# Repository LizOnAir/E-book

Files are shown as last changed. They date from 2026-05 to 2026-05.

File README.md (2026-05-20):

# E-ink Devboard

This devboard is made to be a e-book that can connect to E-ink display, which make reading more easier and accessible.

## Features:
- low power consume rate
- read offline
- download books online
- no bluelight (YOU CAN READ BEFORE BED)

## CAD Model:
Screenshot 2026-05-19 at 6 27 47 PM
Screenshot 2026-05-19 at 6 27 56 PM
Screenshot 2026-05-19 at 6 28 59 PM

Made in Fusion360.Liz
Access files in [CAD folder](https://github.com/LizOnAir/E-book/tree/main/CAD).

## PCB
Here's my PCB! It was made in KiCad. 
### Schematic
Main board

Screenshot 2026-05-19 at 6 37 28 PM

E-ink Display

Screenshot 2026-05-19 at 6 37 42 PM

### PCB
Screenshot 2026-05-19 at 6 38 33 PM

Access files in [PCB folder](https://github.com/LizOnAir/E-book/tree/main/PCB).

## Firmware
I used Arduino IDE
Mode:
- download books
- add bookmark
- read

Access files in [Firmware folder](https://github.com/LizOnAir/E-book/tree/main/Firmware).

## BOM:
Here should be [everything](https://docs.google.com/spreadsheets/d/18-F1pZoXSL668FSytOyo6Q79A_xbLm0seJzbwmDT4q4/edit?gid=0#gid=0) you need to make this:
- 1x PCBA
- 1x 3.7V Lipo Battery 500mAh
- 1x Tactile buttons
- 1x 7.5 inch E-ink display
- 4x M3 14mm Screws
- 4x M3 OD4.2 L 4 Heatset inserts
- 1x 3d printed case

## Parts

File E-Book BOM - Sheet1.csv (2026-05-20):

Name | Quantity | Price | Source
PCBA | 1 | $56.70 | https://cart.jlcpcb.com/quote?spm=jlcpcb.Public.2006
3.7V Lipo Battery 3000mAh | 1 | $6.63 | https://www.aliexpress.com/item/1005008218024646.html
Tactile buttons | 1 | $1.25 | https://www.aliexpress.com/item/1005006880995108.html
7.5 inch E-ink Display | 1 | $20.90 | https://www.aliexpress.com/item/1005002297292956.html?curPageLogUid=uEnQHYUjn61n
M3 14mm Screws | 1 | $1.26 | https://www.aliexpress.com/item/1005007264845313.html
M3 OD4.2 L 4 Heatset inserts | 1 | $1.05 | https://www.aliexpress.com/item/1005007659182107.html
Total |  | $87.79

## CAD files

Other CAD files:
CAD/E-inkPCB.step
CAD/E-book.f3z

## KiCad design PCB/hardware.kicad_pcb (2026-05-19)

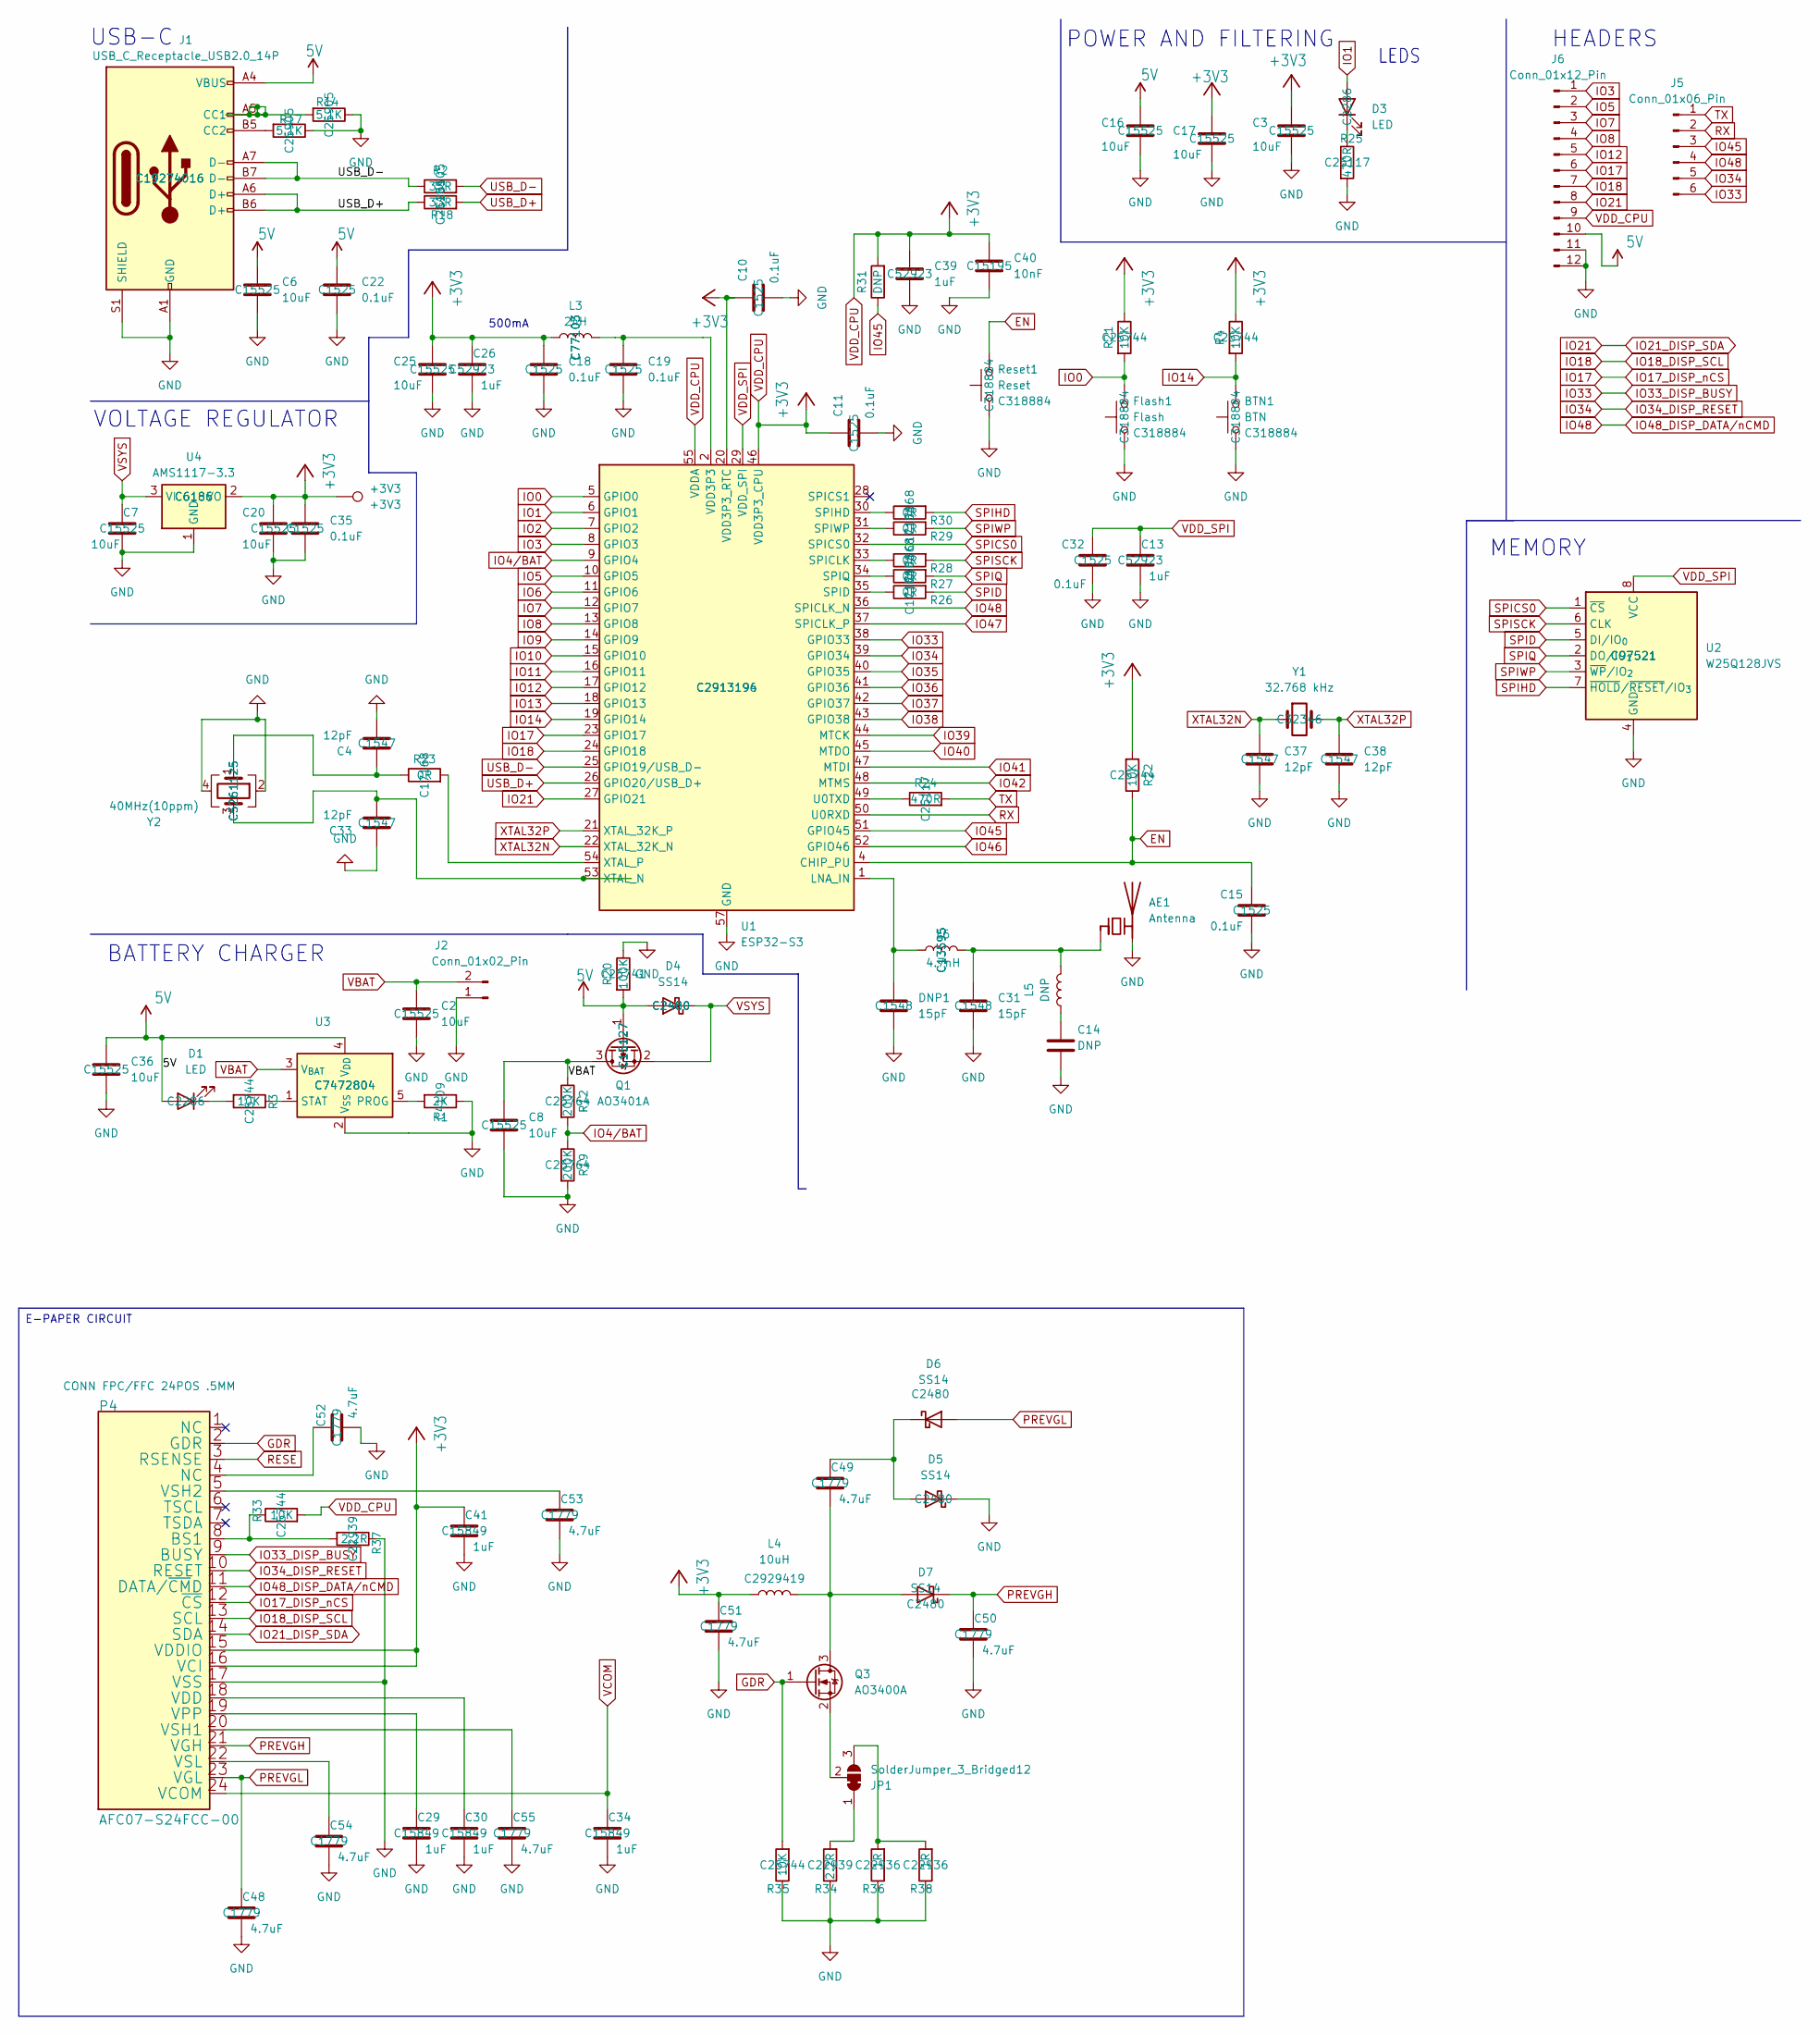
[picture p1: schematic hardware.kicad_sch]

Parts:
+3V3: +3V3; TestPoint_Pad_D1.0mm
AE1: Antenna; Texas_SWRA117D_2.4GHz_Left
BTN1: BTN; SW_Push_1P1T_XKB_TS-1187A; MNF PART NUMBER C318884; LCSC C318884
C2, C3, C6, C7, C8, C16, C17, C20, C25, C36: 10uF; C_0402_1005Metric; MNF PART NUMBER C15525; LCSC C15525
C4, C33, C37, C38: 12pF; C_0402_1005Metric; MNF PART NUMBER C1547; LCSC C1547
C10, C11, C15, C18, C19, C22, C32, C35: 0.1uF; C_0402_1005Metric; MNF PART NUMBER C1525; LCSC C1525
C13, C26, C39: 1uF; C_0402_1005Metric; MNF PART NUMBER C52923; LCSC C52923
C14: DNP; C_0402_1005Metric
C29, C30, C34, C41: 1uF; C_0603_1608Metric; MNF PART NUMBER C15849; LCSC C15849
C31: 15pF; C_0402_1005Metric; MNF PART NUMBER C1548; LCSC C1548
C40: 10nF; C_0402_1005Metric; MNF PART NUMBER C15195; LCSC C15195
C48, C49, C50, C51, C52, C53, C54, C55: 4.7uF; C_0805_2012Metric; MNF PART NUMBER C1779; LCSC C1779
D1, D3: LED; LED_0603_1608Metric; MNF PART NUMBER C2286; LCSC C2286
D4, D5, D6, D7: SS14; D_SMA; MNF PART NUMBER C2480; LCSC C2480
DNP1: 15pF; C_0402_1005Metric; MNF PART NUMBER C1548; LCSC C1548
Flash1: Flash; SW_Push_1P1T_XKB_TS-1187A; MNF PART NUMBER C318884; LCSC C318884
J1: USB_C_Receptacle_USB2.0_14P; USB_C_Receptacle_HCTL_HC-TYPE-C-16P-01A; MNF PART NUMBER C19274016; LCSC C19274016
J2: Conn_01x02_Pin; JST_PH_S2B-PH-K_1x02_P2.00mm_Horizontal
J5: Conn_01x06_Pin; PinHeader_1x06_P1.00mm_Vertical
J6: Conn_01x12_Pin; PinHeader_1x12_P1.00mm_Vertical
JP1: SolderJumper_3_Bridged12; SolderJumper-3_P1.3mm_Bridged12_RoundedPad1.0x1.5mm_NumberL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
L3: 2nH; L_0402_1005Metric; MNF PART NUMBER C77103; LCSC C77103
L4: 10uH; L_Ferrocore_DLG-0403; MNF PART NUMBER C2929419; LCSC C2929419
L5: DNP; L_0402_1005Metric
L6: 4.7nH; L_0402_1005Metric; MNF PART NUMBER C13595; LCSC C13595
P4: AFC07-S24FCC-00; Jushuo_AFC07-S24FCA-00_1x24-1MP_P0.50_Horizontal; MNF PART NUMBER C11057; LCSC C11057
Q1: AO3401A; SOT-23; MNF PART NUMBER C15127; LCSC C15127
Q3: AO3400A; SOT-23; MNF PART NUMBER C20917; LCSC C20917
R1: 2K; R_0402_1005Metric; MNF PART NUMBER C4109; LCSC C4109
R2, R18: 33R; R_0402_1005Metric; MNF PART NUMBER C25105; LCSC C25105
R3, R4, R21, R22, R33, R35: 10K; R_0402_1005Metric; MNF PART NUMBER C25744; LCSC C25744
R12, R19: 200K; R_0402_1005Metric; MNF PART NUMBER C25764; LCSC C25764
R14, R17: 5.1K; R_0402_1005Metric; MNF PART NUMBER C25905; LCSC C25905
R20: 100K; R_0402_1005Metric; MNF PART NUMBER C25741; LCSC C25741
R23, R26, R27, R28, R29, R30: 0R; R_0402_1005Metric; MNF PART NUMBER C17168; LCSC C17168
R24, R25: 470R; R_0402_1005Metric; MNF PART NUMBER C25117; LCSC C25117
R31: DNP; R_0402_1005Metric
R34, R37: 2.2R; R_0603_1608Metric; MNF PART NUMBER C22939; LCSC C22939
R36, R38: 1R; R_0603_1608Metric; MNF PART NUMBER C22936; LCSC C22936
Reset1: Reset; SW_Push_1P1T_XKB_TS-1187A; MNF PART NUMBER C318884; LCSC C318884
U1: ESP32-S3; QFN-56-1EP_7x7mm_P0.4mm_EP4x4mm; MNF PART NUMBER C2913196; LCSC C2913194
U2: W25Q128JVS; SOIC-8_5.3x5.3mm_P1.27mm; MNF PART NUMBER C97521; LCSC C97521
U3: MCP73831-2-OT; SOT-23-5; MNF PART NUMBER C7472804; LCSC C7472804
U4: AMS1117-3.3; SOT-223-3_TabPin2; MNF PART NUMBER C6186; LCSC C6186
Y1: 32.768 kHz; Crystal_SMD_3215-2Pin_3.2x1.5mm; MNF PART NUMBER C32346; LCSC C32346
Y2: 40MHz(10ppm); Crystal_SMD_2520-4Pin_2.5x2.0mm; MNF PART NUMBER C5261125; LCSC C5261125

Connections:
5V: C6.1, C16.1, C22.1, C36.1, D1.2 (A), D4.2 (A), J1.A4 (VBUS), J1.A9 (VBUS), J1.B4 (VBUS), J1.B9 (VBUS), J6.10, Q1.1 (G), R20.2, U3.4 (V_{DD})
EN: C15.1, R22.1, Reset1.2, U1.4 (CHIP_PU)
GDR: P4.2 (GDR), Q3.1 (G), R35.2
GND: AE1.2 (PCB_Trace), BTN1.1, C2.2, C3.2, C4.2, C6.2, C7.2, C8.2, C10.2, C11.2, C13.2, C14.2, C15.2, C16.2, C17.2, C18.2, C19.2, C20.2, C22.2, C25.2, C26.2, C29.2, C30.2, C31.2, C32.2, C33.1, C34.2, C35.2, C36.2, C37.2, C38.2, C39.2, C40.2, C41.2, C48.2, C50.2, C51.2, C52.2, C53.2, C54.2, C55.2, D5.1 (K), DNP1.2, Flash1.1, J1.A1 (GND), J1.A12 (GND), J1.B1 (GND), J1.B12 (GND), J1.S1 (SHIELD), J2.1, J6.11, J6.12, P4.17 (VSS), R1.1, R14.1, R17.1, R19.2, R20.1, R25.2, R34.1, R35.1, R36.1, R37.1, R38.1, Reset1.1, U1.57 (GND), U2.4 (GND), U3.2 (V_{SS}), U4.1 (GND), Y2.2, Y2.4
IO0: Flash1.2, R21.2, U1.5 (GPIO0)
IO1: D3.2 (A), U1.6 (GPIO1)
IO2: U1.7 (GPIO2)
IO3: J6.1, U1.8 (GPIO3)
IO4/BAT: R12.2, R19.1, U1.9 (GPIO4)
IO5: J6.2, U1.10 (GPIO5)
IO6: U1.11 (GPIO6)
IO7: J6.3, U1.12 (GPIO7)
IO8: J6.4, U1.13 (GPIO8)
IO9: U1.14 (GPIO9)
IO10: U1.15 (GPIO10)
IO11: U1.16 (GPIO11)
IO12: J6.5, U1.17 (GPIO12)
IO13: U1.18 (GPIO13)
IO14: BTN1.2, R4.2, U1.19 (GPIO14)
IO17: J6.6, P4.12 (~CS), U1.23 (GPIO17)
IO18: J6.7, P4.13 (SCL), U1.24 (GPIO18)
IO21: J6.8, P4.14 (SDA), U1.27 (GPIO21)
IO33: J5.6, P4.9 (BUSY), U1.38 (GPIO33)
IO34: J5.5, P4.10 (RESET), U1.39 (GPIO34)
IO35: U1.40 (GPIO35)
IO36: U1.41 (GPIO36)
IO37: U1.42 (GPIO37)
IO38: U1.43 (GPIO38)
IO39: U1.44 (MTCK)
IO40: U1.45 (MTDO)
IO41: U1.47 (MTDI)
IO42: U1.48 (MTMS)
IO45: J5.3, R31.1, U1.51 (GPIO45)
IO46: U1.52 (GPIO46)
IO47: U1.37 (SPICLK_P)
IO48: J5.4, P4.11 (DATA/~CMD), U1.36 (SPICLK_N)
unnamed: AE1.1 (FEED), C31.1, L5.2, L6.2
unnamed: C4.1, R23.1, Y2.1
unnamed: C14.1, L5.1
unnamed: C19.1, L3.2, U1.2 (VDD3P3), U1.3 (VDD3P3)
unnamed: C52.1, P4.4 (NC)
unnamed: D1.1 (K), R3.2
unnamed: D3.1 (K), R25.1
unnamed: C49.1, D5.2 (A), D6.1 (K)
unnamed: C49.2, D7.2 (A), L4.2, Q3.3 (D)
unnamed: J1.A5 (CC1), R14.2
unnamed: J1.B5 (CC2), R17.2
unnamed: JP1.1 (A), R34.2
unnamed: JP1.3 (B), R36.2, R38.2
unnamed: JP1.2 (C), Q3.2 (S)
unnamed: P4.8 (BS1), R33.1, R37.2
unnamed: C30.1, P4.18 (VDD)
unnamed: C29.1, P4.19 (VPP)
unnamed: C55.1, P4.20 (VSH1)
unnamed: C53.1, P4.5 (VSH2)
unnamed: C54.1, P4.22 (VSL)
unnamed: DNP1.1, L6.1, U1.1 (LNA_IN)
unnamed: R28.1, U1.33 (SPICLK)
unnamed: R26.1, U1.35 (SPID)
unnamed: R30.1, U1.30 (SPIHD)
unnamed: R27.1, U1.34 (SPIQ)
unnamed: R29.1, U1.31 (SPIWP)
unnamed: R24.1, U1.49 (U0TXD)
unnamed: C33.2, U1.53 (XTAL_N), Y2.3
unnamed: R23.2, U1.54 (XTAL_P)
unnamed: R1.2, U3.5 (PROG)
unnamed: R3.1, U3.1 (STAT)
PREVGH: C50.1, D7.1 (K), P4.21 (VGH)
PREVGL: C48.1, D6.2 (A), P4.23 (VGL)
RESE: P4.3 (RSENSE)
RX: J5.2, U1.50 (U0RXD)
SPICS0: U1.32 (SPICS0), U2.1 (~CS)
SPID: R26.2, U2.5 (DI/IO_{0})
SPIHD: R30.2, U2.7 (~HOLD/~RESET/IO_{3})
SPIQ: R27.2, U2.2 (DO/IO_{1})
SPISCK: R28.2, U2.6 (CLK)
SPIWP: R29.2, U2.3 (~WP/IO_{2})
TX: J5.1, R24.2
USB_D+: J1.A6 (D+), J1.B6 (D+), R18.1, R18.2, U1.26 (GPIO20/USB_D+)
USB_D-: J1.A7 (D-), J1.B7 (D-), R2.1, R2.2, U1.25 (GPIO19/USB_D-)
VBAT: C2.1, C8.1, J2.2, Q1.3 (D), R12.1, U3.3 (V_{BAT})
VCOM: C34.1, P4.24 (VCOM)
VDD_CPU: +3V3.1, C3.1, C10.1, C11.1, C17.1, C18.1, C20.1, C25.1, C26.1, C35.1, C39.1, C40.1, C41.1, C51.1, J6.9, L3.1, L4.1, P4.15 (VDDIO), P4.16 (VCI), R4.1, R21.1, R22.2, R31.2, R33.2, U1.20 (VDD3P3_RTC), U1.46 (VDD3P3_CPU), U1.55 (VDDA), U1.56 (VDDA), U4.2 (VO)
VDD_SPI: C13.1, C32.1, U1.29 (VDD_SPI), U2.8 (VCC)
VSYS: C7.1, D4.1 (K), Q1.2 (S), U4.3 (VI)
XTAL32N: C37.1, U1.22 (XTAL_32K_N), Y1.1
XTAL32P: C38.1, U1.21 (XTAL_32K_P), Y1.2

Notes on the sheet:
500mA
BATTERY CHARGER
VOLTAGE REGULATOR
LEDS
HEADERS
MEMORY
POWER AND FILTERING
USB-C
E-PAPER CIRCUIT

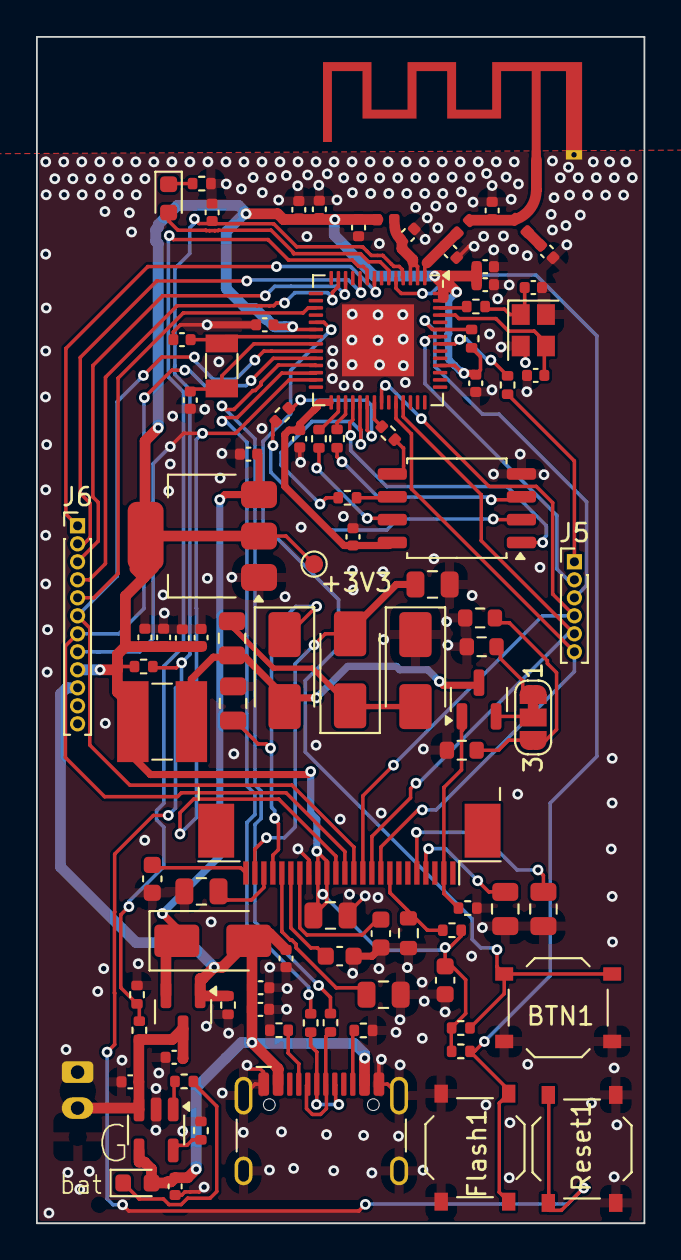
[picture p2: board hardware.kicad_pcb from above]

Board: 2 copper layers, 33.8 x 65.9 mm, 97 parts (1 on the bottom side), 70 nets.

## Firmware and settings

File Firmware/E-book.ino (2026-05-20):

#include <WiFi.h>
#include <HTTPClient.h>
#include <FS.h>
#include <SPIFFS.h>
#include <GxEPD2_BW.h>
#include <Adafruit_GFX.h>

// Wi-Fi Settings
const char* ssid = "YOUR_WIFI_SSID";
const char* password = "YOUR_WIFI_PASSWORD";
const char* bookServerUrl = "http://your-server-ip/books/book1.txt"; //example

// Pin Definitions
#define BUTTON_PIN 14
#define EPD_CS     5
#define EPD_DC     17
#define EPD_RST    16
#define EPD_BUSY   4

// E-Ink Display Setup (7.5 inch GDEH075Z90) 
GxEPD2_BW<GxEPD2_750_GDEHY075TT1, GxEPD2_750_GDEHY075TT1::HEIGHT> display(GxEPD2_750_GDEHY075TT1(EPD_CS, EPD_DC, EPD_RST, EPD_BUSY));

// State
enum AppState { MENU, READING, DOWNLOADING };
AppState currentState = MENU;

//  Menu 
const int totalMenuOptions = 3;
const char* menuOptions[totalMenuOptions] = {
  "1. Read Book",
  "2. Download New Book",
  "3. Load Bookmark"
};
int currentMenuSelection = 0;

// Button timing for Short vs Long press
unsigned long buttonPressStartTime = 0;
const unsigned long longPressDuration = 800; // milliseconds for select
bool lastButtonState = HIGH;

//  Function Prototypes 
void initDisplay();
void drawMenu();
void handleButton();
void downloadBook();
void readBook(bool lookupBookmark);
void saveBookmark(int pagePosition);
int loadBookmark();

void setup() {
  Serial.begin(115200);
  pinMode(BUTTON_PIN, INPUT_PULLUP);

  if (!SPIFFS.begin(true)) {
    Serial.println("SPIFFS Mount Failed");
    return;
  }

  initDisplay();
  drawMenu();
}

void loop() {
  handleButton();
  delay(10); // Debounce / stability delay
}

// Display Initialization 
void initDisplay() {
  display.init(115200);
  display.setRotation(1);
  display.setTextColor(GxEPD_BLACK);
  display.setBackgroundColor(GxEPD_WHITE);
}

// UI Rendering 
void drawMenu() {
  display.setFullWindow();
  display.firstPage();
  do {
    display.fillScreen(GxEPD_WHITE);
    display.setTextSize(3);
    display.setCursor(50, 50);
    display.println(" ESP32 E-READER ");
    display.drawFastHLine(50, 70, 700, GxEPD_BLACK);

    display.setTextSize(2);
    for (int i = 0; i < totalMenuOptions; i++) {
      int yPos = 140 + (i * 60);
      if (i == currentMenuSelection) {
        display.fillRect(45, yPos - 10, 600, 40, GxEPD_BLACK);
        display.setTextColor(GxEPD_WHITE);
      } else {
        display.setTextColor(GxEPD_BLACK);
      }
      display.setCursor(60, yPos);
      display.println(menuOptions[i]);
    }
  } while (display.nextPage());
}

// Button Handling (Multi-click & Long Press) 
void handleButton() {
  bool currentButtonState = digitalRead(BUTTON_PIN);

  // Button Pressed Down
  if (lastButtonState == HIGH && currentButtonState == LOW) {
    buttonPressStartTime = millis();
  }
  
  // Button Released
  if (lastButtonState == LOW && currentButtonState == HIGH) {
    unsigned long pressDuration = millis() - buttonPressStartTime;

    if (pressDuration >= longPressDuration) {
      // LONG PRESS -> TRIGGER ACTION
      executeSelection();
    } else {
      // SHORT PRESS -> NEXT
      if (currentState == MENU) {
        currentMenuSelection = (currentMenuSelection + 1) % totalMenuOptions;
        drawMenu();
      } else {
        // If reading, short press acts as turning the page or returning to menu
        currentState = MENU;
        drawMenu();
      }
    }
  }
  lastButtonState = currentButtonState;
}

//  Menu Action Executor 
void executeSelection() {
  if (currentState == MENU) {
    if (currentMenuSelection == 0) {
      readBook(false); // Read from beginning
    } else if (currentMenuSelection == 1) {
      downloadBook();
    } else if (currentMenuSelection == 2) {
      readBook(true);  // Read from saved bookmark
    }
  }
}

// WiFi & Network Operations 
void downloadBook() {
  currentState = DOWNLOADING;
  Serial.println("Connecting to WiFi...");
  
  WiFi.begin(ssid, password);
  int attempts = 0;
  while (WiFi.status() != WL_CONNECTED && attempts < 20) {
    delay(500);
    attempts++;
  }

  if (WiFi.status() != WL_CONNECTED) {
    Serial.println("WiFi Connection Failed");
    currentState = MENU;
    drawMenu();
    return;
  }

  HTTPClient http;
  http.begin(bookServerUrl);
  int httpCode = http.GET();

  if (httpCode == HTTP_CODE_OK) {
    File file = SPIFFS.open("/book.txt", FILE_WRITE);
    if (file) {
      http.writeToStream(&file);
      file.close();
      Serial.println("Book downloaded successfully!");
    }
  } else {
    Serial.printf("HTTP GET failed, error: %s\n", http.errorToString(httpCode).c_str());
  }
  
  http.end();
  WiFi.disconnect(true);
  
  currentState = MENU;
  drawMenu();
}

// Storage & Book Reading Operations 
void readBook(bool lookupBookmark) {
  currentState = READING;
  
  if (!SPIFFS.exists("/book.txt")) {
    Serial.println("No book found. Please download one first.");
    currentState = MENU;
    drawMenu();
    return;
  }

  File file = SPIFFS.open("/book.txt", FILE_READ);
  int startPosition = 0;

  if (lookupBookmark) {
    startPosition = loadBookmark();
    file.seek(startPosition);
  }

  // Read a chunk of text to display on the screen
  String bookPage = "";
  for (int i = 0; i < 500 && file.available(); i++) {
    bookPage += (char)file.read();
  }
  
  int nextBookmarkPos = file.position();
  file.close();

  // Save progress automatically
  saveBookmark(nextBookmarkPos);

  // Render Page to E-Ink
  display.setFullWindow();
  display.firstPage();
  do {
    display.fillScreen(GxEPD_WHITE);
    display.setTextColor(GxEPD_BLACK);
    display.setTextSize(2);
    display.setCursor(30, 40);
    display.println(" Reading: book.txt ");
    display.setCursor(30, 90);
    display.println(bookPage.c_str());
    display.setTextSize(1);
    display.setCursor(30, 450);
    display.print("[Short Press to Exit | Progress Saved]");
  } while (display.nextPage());
}

void saveBookmark(int pagePosition) {
  File bookmarkFile = SPIFFS.open("/bookmark.txt", FILE_WRITE);
  if (bookmarkFile) {
    bookmarkFile.print(pagePosition);
    bookmarkFile.close();
    Serial.printf("Bookmark saved at byte: %d\n", pagePosition);
  }
}

int loadBookmark() {
  if (!SPIFFS.exists("/bookmark.txt")) return 0;
  
  File bookmarkFile = SPIFFS.open("/bookmark.txt", FILE_READ);
  if (bookmarkFile) {
    String posStr = bookmarkFile.readString();
    bookmarkFile.close();
    return posStr.toInt();
  }
  return 0;
}
